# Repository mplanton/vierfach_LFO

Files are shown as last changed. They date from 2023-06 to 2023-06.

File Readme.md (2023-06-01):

# Vierfach LFO Eurorack Module

This is a quadruple LFO eurorack module.
The original LFO schematic is found in Barry Klein's [Electronic music circuits](https://archive.org/details/electronic-music-circuits/page/n71/mode/2up) on page 70.

Every LFO features a switchable output for pulse, triangle or sine.

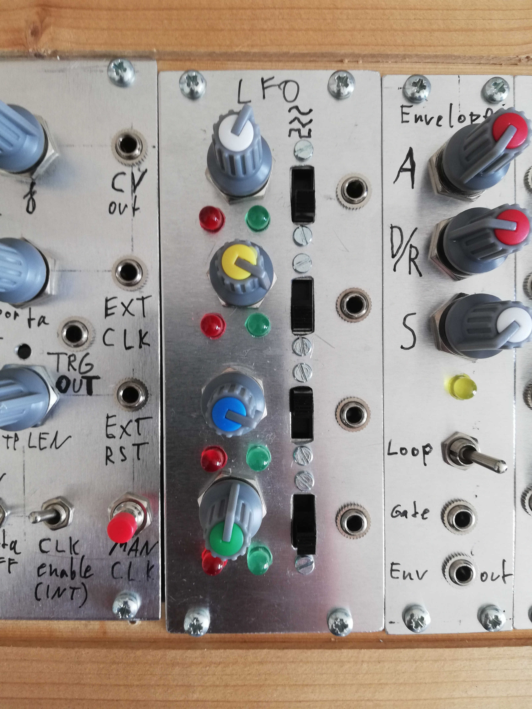
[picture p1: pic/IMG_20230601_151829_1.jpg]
Vierfach LFO module.


See the [pictures](pic/) for the assembly process.
The module is a rough prototype I built for my own purposes and I hope you may find it useful for your own projects.

Manuel Planton 2022

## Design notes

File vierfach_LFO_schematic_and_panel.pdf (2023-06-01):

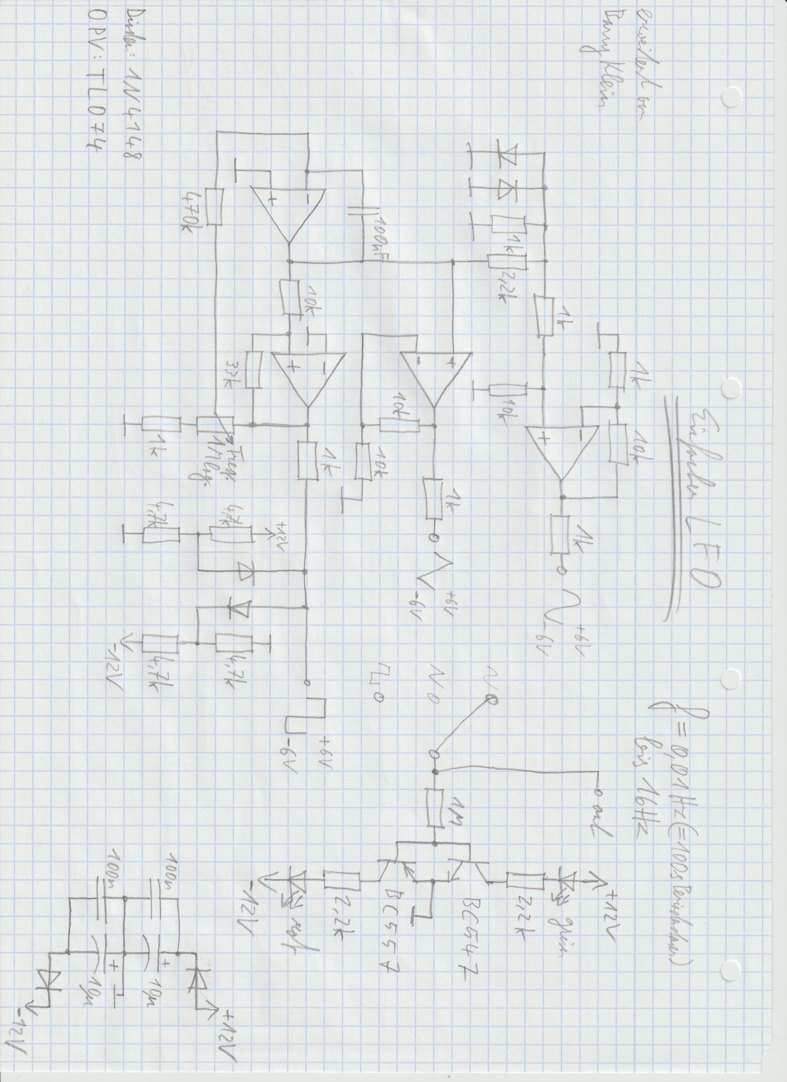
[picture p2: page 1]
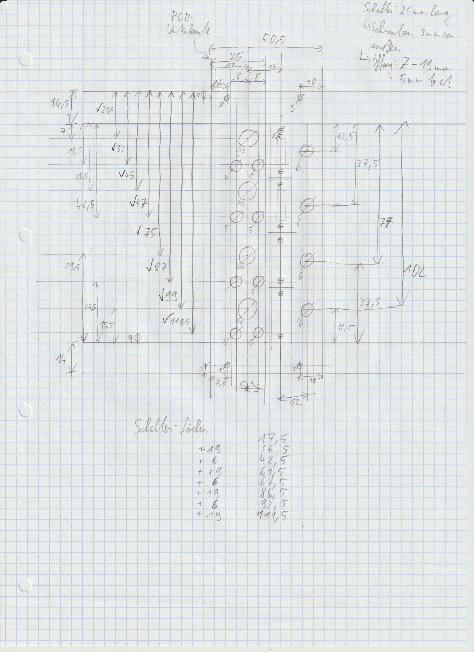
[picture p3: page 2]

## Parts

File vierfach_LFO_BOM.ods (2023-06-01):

Reference | Value | Footprint
C101 | 10u | Capacitor_THT:CP_Radial_D5.0mm_P2.50mm
C102 | 10u | Capacitor_THT:CP_Radial_D5.0mm_P2.50mm
C201 | 100n | Capacitor_SMD:C_0805_2012Metric_Pad1.18x1.45mm_HandSolder
C202 | 100n | Capacitor_SMD:C_0805_2012Metric_Pad1.18x1.45mm_HandSolder
C203 | 100n | Capacitor_SMD:C_0805_2012Metric_Pad1.18x1.45mm_HandSolder
C301 | 100n | Capacitor_SMD:C_0805_2012Metric_Pad1.18x1.45mm_HandSolder
C302 | 100n | Capacitor_SMD:C_0805_2012Metric_Pad1.18x1.45mm_HandSolder
C303 | 100n | Capacitor_SMD:C_0805_2012Metric_Pad1.18x1.45mm_HandSolder
C401 | 100n | Capacitor_SMD:C_0805_2012Metric_Pad1.18x1.45mm_HandSolder
C402 | 100n | Capacitor_SMD:C_0805_2012Metric_Pad1.18x1.45mm_HandSolder
C403 | 100n | Capacitor_SMD:C_0805_2012Metric_Pad1.18x1.45mm_HandSolder
C501 | 100n | Capacitor_SMD:C_0805_2012Metric_Pad1.18x1.45mm_HandSolder
C502 | 100n | Capacitor_SMD:C_0805_2012Metric_Pad1.18x1.45mm_HandSolder
C503 | 100n | Capacitor_SMD:C_0805_2012Metric_Pad1.18x1.45mm_HandSolder
R202 | 10k | Resistor_SMD:R_0805_2012Metric_Pad1.20x1.40mm_HandSolder
R207 | 10k | Resistor_SMD:R_0805_2012Metric_Pad1.20x1.40mm_HandSolder
R212 | 10k | Resistor_SMD:R_0805_2012Metric_Pad1.20x1.40mm_HandSolder
R213 | 10k | Resistor_SMD:R_0805_2012Metric_Pad1.20x1.40mm_HandSolder
R215 | 10k | Resistor_SMD:R_0805_2012Metric_Pad1.20x1.40mm_HandSolder
R201 | 1k | Resistor_SMD:R_0805_2012Metric_Pad1.20x1.40mm_HandSolder
R204 | 1k | Resistor_THT:R_Axial_DIN0207_L6.3mm_D2.5mm_P10.16mm_Horizontal
R205 | 1k | Resistor_SMD:R_0805_2012Metric_Pad1.20x1.40mm_HandSolder
R208 | 1k | Resistor_SMD:R_0805_2012Metric_Pad1.20x1.40mm_HandSolder
R211 | 1k | Resistor_THT:R_Axial_DIN0207_L6.3mm_D2.5mm_P10.16mm_Horizontal
R214 | 1k | Resistor_THT:R_Axial_DIN0207_L6.3mm_D2.5mm_P10.16mm_Horizontal
R222 | 1k | Resistor_SMD:R_0805_2012Metric_Pad1.20x1.40mm_HandSolder
R206 | 1M | Resistor_SMD:R_0805_2012Metric_Pad1.20x1.40mm_HandSolder
R203 | 2.2k | Resistor_SMD:R_0805_2012Metric_Pad1.20x1.40mm_HandSolder
R209 | 2.2k | Resistor_SMD:R_0805_2012Metric_Pad1.20x1.40mm_HandSolder
R210 | 2.2k | Resistor_SMD:R_0805_2012Metric_Pad1.20x1.40mm_HandSolder
R218 | 33k | Resistor_SMD:R_0805_2012Metric_Pad1.20x1.40mm_HandSolder
R216 | 4.7k | Resistor_SMD:R_0805_2012Metric_Pad1.20x1.40mm_HandSolder
R217 | 4.7k | Resistor_SMD:R_0805_2012Metric_Pad1.20x1.40mm_HandSolder
R219 | 4.7k | Resistor_SMD:R_0805_2012Metric_Pad1.20x1.40mm_HandSolder
R220 | 4.7k | Resistor_SMD:R_0805_2012Metric_Pad1.20x1.40mm_HandSolder
R221 | 470k | Resistor_SMD:R_0805_2012Metric_Pad1.20x1.40mm_HandSolder
R302 | 10k | Resistor_SMD:R_0805_2012Metric_Pad1.20x1.40mm_HandSolder
R307 | 10k | Resistor_SMD:R_0805_2012Metric_Pad1.20x1.40mm_HandSolder
R312 | 10k | Resistor_SMD:R_0805_2012Metric_Pad1.20x1.40mm_HandSolder
R313 | 10k | Resistor_SMD:R_0805_2012Metric_Pad1.20x1.40mm_HandSolder
R315 | 10k | Resistor_SMD:R_0805_2012Metric_Pad1.20x1.40mm_HandSolder
R301 | 1k | Resistor_SMD:R_0805_2012Metric_Pad1.20x1.40mm_HandSolder
R304 | 1k | Resistor_THT:R_Axial_DIN0207_L6.3mm_D2.5mm_P10.16mm_Horizontal
R305 | 1k | Resistor_SMD:R_0805_2012Metric_Pad1.20x1.40mm_HandSolder
R308 | 1k | Resistor_SMD:R_0805_2012Metric_Pad1.20x1.40mm_HandSolder
R311 | 1k | Resistor_THT:R_Axial_DIN0207_L6.3mm_D2.5mm_P10.16mm_Horizontal
R314 | 1k | Resistor_THT:R_Axial_DIN0207_L6.3mm_D2.5mm_P10.16mm_Horizontal
R322 | 1k | Resistor_SMD:R_0805_2012Metric_Pad1.20x1.40mm_HandSolder
R306 | 1M | Resistor_SMD:R_0805_2012Metric_Pad1.20x1.40mm_HandSolder
R303 | 2.2k | Resistor_SMD:R_0805_2012Metric_Pad1.20x1.40mm_HandSolder
R309 | 2.2k | Resistor_SMD:R_0805_2012Metric_Pad1.20x1.40mm_HandSolder
R310 | 2.2k | Resistor_SMD:R_0805_2012Metric_Pad1.20x1.40mm_HandSolder
R318 | 33k | Resistor_SMD:R_0805_2012Metric_Pad1.20x1.40mm_HandSolder
R316 | 4.7k | Resistor_SMD:R_0805_2012Metric_Pad1.20x1.40mm_HandSolder
R317 | 4.7k | Resistor_SMD:R_0805_2012Metric_Pad1.20x1.40mm_HandSolder
R319 | 4.7k | Resistor_SMD:R_0805_2012Metric_Pad1.20x1.40mm_HandSolder
R320 | 4.7k | Resistor_SMD:R_0805_2012Metric_Pad1.20x1.40mm_HandSolder
R321 | 470k | Resistor_SMD:R_0805_2012Metric_Pad1.20x1.40mm_HandSolder
R402 | 10k | Resistor_SMD:R_0805_2012Metric_Pad1.20x1.40mm_HandSolder
R407 | 10k | Resistor_SMD:R_0805_2012Metric_Pad1.20x1.40mm_HandSolder
R412 | 10k | Resistor_SMD:R_0805_2012Metric_Pad1.20x1.40mm_HandSolder
R413 | 10k | Resistor_SMD:R_0805_2012Metric_Pad1.20x1.40mm_HandSolder
R415 | 10k | Resistor_SMD:R_0805_2012Metric_Pad1.20x1.40mm_HandSolder
R401 | 1k | Resistor_SMD:R_0805_2012Metric_Pad1.20x1.40mm_HandSolder
R404 | 1k | Resistor_THT:R_Axial_DIN0207_L6.3mm_D2.5mm_P10.16mm_Horizontal
R405 | 1k | Resistor_SMD:R_0805_2012Metric_Pad1.20x1.40mm_HandSolder
R408 | 1k | Resistor_SMD:R_0805_2012Metric_Pad1.20x1.40mm_HandSolder
R411 | 1k | Resistor_THT:R_Axial_DIN0207_L6.3mm_D2.5mm_P10.16mm_Horizontal
R414 | 1k | Resistor_THT:R_Axial_DIN0207_L6.3mm_D2.5mm_P10.16mm_Horizontal
R422 | 1k | Resistor_SMD:R_0805_2012Metric_Pad1.20x1.40mm_HandSolder
R406 | 1M | Resistor_SMD:R_0805_2012Metric_Pad1.20x1.40mm_HandSolder
R403 | 2.2k | Resistor_SMD:R_0805_2012Metric_Pad1.20x1.40mm_HandSolder
R409 | 2.2k | Resistor_SMD:R_0805_2012Metric_Pad1.20x1.40mm_HandSolder
R410 | 2.2k | Resistor_SMD:R_0805_2012Metric_Pad1.20x1.40mm_HandSolder
R418 | 33k | Resistor_SMD:R_0805_2012Metric_Pad1.20x1.40mm_HandSolder
R416 | 4.7k | Resistor_SMD:R_0805_2012Metric_Pad1.20x1.40mm_HandSolder
R417 | 4.7k | Resistor_SMD:R_0805_2012Metric_Pad1.20x1.40mm_HandSolder
R419 | 4.7k | Resistor_SMD:R_0805_2012Metric_Pad1.20x1.40mm_HandSolder
R420 | 4.7k | Resistor_SMD:R_0805_2012Metric_Pad1.20x1.40mm_HandSolder
R421 | 470k | Resistor_SMD:R_0805_2012Metric_Pad1.20x1.40mm_HandSolder
R502 | 10k | Resistor_SMD:R_0805_2012Metric_Pad1.20x1.40mm_HandSolder
R507 | 10k | Resistor_SMD:R_0805_2012Metric_Pad1.20x1.40mm_HandSolder
R512 | 10k | Resistor_SMD:R_0805_2012Metric_Pad1.20x1.40mm_HandSolder
R513 | 10k | Resistor_SMD:R_0805_2012Metric_Pad1.20x1.40mm_HandSolder
R515 | 10k | Resistor_SMD:R_0805_2012Metric_Pad1.20x1.40mm_HandSolder
R501 | 1k | Resistor_SMD:R_0805_2012Metric_Pad1.20x1.40mm_HandSolder
R504 | 1k | Resistor_THT:R_Axial_DIN0207_L6.3mm_D2.5mm_P10.16mm_Horizontal
R505 | 1k | Resistor_SMD:R_0805_2012Metric_Pad1.20x1.40mm_HandSolder
R508 | 1k | Resistor_SMD:R_0805_2012Metric_Pad1.20x1.40mm_HandSolder
R511 | 1k | Resistor_THT:R_Axial_DIN0207_L6.3mm_D2.5mm_P10.16mm_Horizontal
R514 | 1k | Resistor_THT:R_Axial_DIN0207_L6.3mm_D2.5mm_P10.16mm_Horizontal
R522 | 1k | Resistor_SMD:R_0805_2012Metric_Pad1.20x1.40mm_HandSolder
R506 | 1M | Resistor_SMD:R_0805_2012Metric_Pad1.20x1.40mm_HandSolder
R503 | 2.2k | Resistor_SMD:R_0805_2012Metric_Pad1.20x1.40mm_HandSolder
R509 | 2.2k | Resistor_SMD:R_0805_2012Metric_Pad1.20x1.40mm_HandSolder
R510 | 2.2k | Resistor_SMD:R_0805_2012Metric_Pad1.20x1.40mm_HandSolder
R518 | 33k | Resistor_SMD:R_0805_2012Metric_Pad1.20x1.40mm_HandSolder
R516 | 4.7k | Resistor_SMD:R_0805_2012Metric_Pad1.20x1.40mm_HandSolder
R517 | 4.7k | Resistor_SMD:R_0805_2012Metric_Pad1.20x1.40mm_HandSolder
R519 | 4.7k | Resistor_SMD:R_0805_2012Metric_Pad1.20x1.40mm_HandSolder
R520 | 4.7k | Resistor_SMD:R_0805_2012Metric_Pad1.20x1.40mm_HandSolder
R521 | 470k | Resistor_SMD:R_0805_2012Metric_Pad1.20x1.40mm_HandSolder
D202 | 1N4148 | Diode_THT:D_DO-35_SOD27_P7.62mm_Horizontal
D203 | 1N4148 | Diode_THT:D_DO-35_SOD27_P7.62mm_Horizontal
D205 | 1N4148 | Diode_THT:D_DO-35_SOD27_P7.62mm_Horizontal
D206 | 1N4148 | Diode_THT:D_DO-35_SOD27_P7.62mm_Horizontal
D302 | 1N4148 | Diode_THT:D_DO-35_SOD27_P7.62mm_Horizontal
D303 | 1N4148 | Diode_THT:D_DO-35_SOD27_P7.62mm_Horizontal
D305 | 1N4148 | Diode_THT:D_DO-35_SOD27_P7.62mm_Horizontal
D306 | 1N4148 | Diode_THT:D_DO-35_SOD27_P7.62mm_Horizontal
D402 | 1N4148 | Diode_THT:D_DO-35_SOD27_P7.62mm_Horizontal
D403 | 1N4148 | Diode_THT:D_DO-35_SOD27_P7.62mm_Horizontal
D405 | 1N4148 | Diode_THT:D_DO-35_SOD27_P7.62mm_Horizontal
D406 | 1N4148 | Diode_THT:D_DO-35_SOD27_P7.62mm_Horizontal
D502 | 1N4148 | Diode_THT:D_DO-35_SOD27_P7.62mm_Horizontal
D503 | 1N4148 | Diode_THT:D_DO-35_SOD27_P7.62mm_Horizontal
D505 | 1N4148 | Diode_THT:D_DO-35_SOD27_P7.62mm_Horizontal
D506 | 1N4148 | Diode_THT:D_DO-35_SOD27_P7.62mm_Horizontal
D101 | 1N5817 | Diode_THT:D_DO-41_SOD81_P10.16mm_Horizontal
D102 | 1N5817 | Diode_THT:D_DO-41_SOD81_P10.16mm_Horizontal
D201 | green | LED_THT:LED_D5.0mm
D301 | green | LED_THT:LED_D5.0mm
D401 | green | LED_THT:LED_D5.0mm
D501 | green | LED_THT:LED_D5.0mm
D204 | red | LED_THT:LED_D5.0mm
D304 | red | LED_THT:LED_D5.0mm
D404 | red | LED_THT:LED_D5.0mm
D504 | red | LED_THT:LED_D5.0mm
Q201 | BC547 | Package_TO_SOT_THT:TO-92_Inline_Wide
Q202 | BC557 | Package_TO_SOT_THT:TO-92_Inline_Wide
Q301 | BC547 | Package_TO_SOT_THT:TO-92_Inline_Wide
Q302 | BC557 | Package_TO_SOT_THT:TO-92_Inline_Wide
Q401 | BC547 | Package_TO_SOT_THT:TO-92_Inline_Wide
Q402 | BC557 | Package_TO_SOT_THT:TO-92_Inline_Wide
Q501 | BC547 | Package_TO_SOT_THT:TO-92_Inline_Wide
Q502 | BC557 | Package_TO_SOT_THT:TO-92_Inline_Wide
R_freq201 | 1M | Potentiometer_THT:Potentiometer_Piher_PC-16_Single_Horizontal
R_freq301 | 1M | Potentiometer_THT:Potentiometer_Piher_PC-16_Single_Horizontal
R_freq401 | 1M | Potentiometer_THT:Potentiometer_Piher_PC-16_Single_Horizontal
R_freq501 | 1M | Potentiometer_THT:Potentiometer_Piher_PC-16_Single_Horizontal
U201 | TL074 | Package_DIP:DIP-14_W7.62mm_Socket
U301 | TL074 | Package_DIP:DIP-14_W7.62mm_Socket
U401 | TL074 | Package_DIP:DIP-14_W7.62mm_Socket
U501 | TL074 | Package_DIP:DIP-14_W7.62mm_Socket
J101 | Conn_02x05_Odd_Even | Connector_PinHeader_2.54mm:PinHeader_2x05_P2.54mm_Vertical
J201 | LEDs_IN_Conn_01x01_Female | Connector_PinHeader_2.54mm:PinHeader_1x01_P2.54mm_Vertical
J202 | sine_OUT_Conn_01x01_Female | Connector_PinHeader_2.54mm:PinHeader_1x01_P2.54mm_Vertical
J203 | tri_OUT_Conn_01x01_Female | Connector_PinHeader_2.54mm:PinHeader_1x01_P2.54mm_Vertical
J204 | square_OUT_Conn_01x01_Female | Connector_PinHeader_2.54mm:PinHeader_1x01_P2.54mm_Vertical
J301 | LEDs_IN_Conn_01x01_Female | Connector_PinHeader_2.54mm:PinHeader_1x01_P2.54mm_Vertical
J302 | sine_OUT_Conn_01x01_Female | Connector_PinHeader_2.54mm:PinHeader_1x01_P2.54mm_Vertical
J303 | tri_OUT_Conn_01x01_Female | Connector_PinHeader_2.54mm:PinHeader_1x01_P2.54mm_Vertical
J304 | square_OUT_Conn_01x01_Female | Connector_PinHeader_2.54mm:PinHeader_1x01_P2.54mm_Vertical
J401 | LEDs_IN_Conn_01x01_Female | Connector_PinHeader_2.54mm:PinHeader_1x01_P2.54mm_Vertical
J402 | sine_OUT_Conn_01x01_Female | Connector_PinHeader_2.54mm:PinHeader_1x01_P2.54mm_Vertical
J403 | tri_OUT_Conn_01x01_Female | Connector_PinHeader_2.54mm:PinHeader_1x01_P2.54mm_Vertical
J404 | square_OUT_Conn_01x01_Female | Connector_PinHeader_2.54mm:PinHeader_1x01_P2.54mm_Vertical
J501 | LEDs_IN_Conn_01x01_Female | Connector_PinHeader_2.54mm:PinHeader_1x01_P2.54mm_Vertical
J502 | sine_OUT_Conn_01x01_Female | Connector_PinHeader_2.54mm:PinHeader_1x01_P2.54mm_Vertical
J503 | tri_OUT_Conn_01x01_Female | Connector_PinHeader_2.54mm:PinHeader_1x01_P2.54mm_Vertical
J504 | square_OUT_Conn_01x01_Female | Connector_PinHeader_2.54mm:PinHeader_1x01_P2.54mm_Vertical

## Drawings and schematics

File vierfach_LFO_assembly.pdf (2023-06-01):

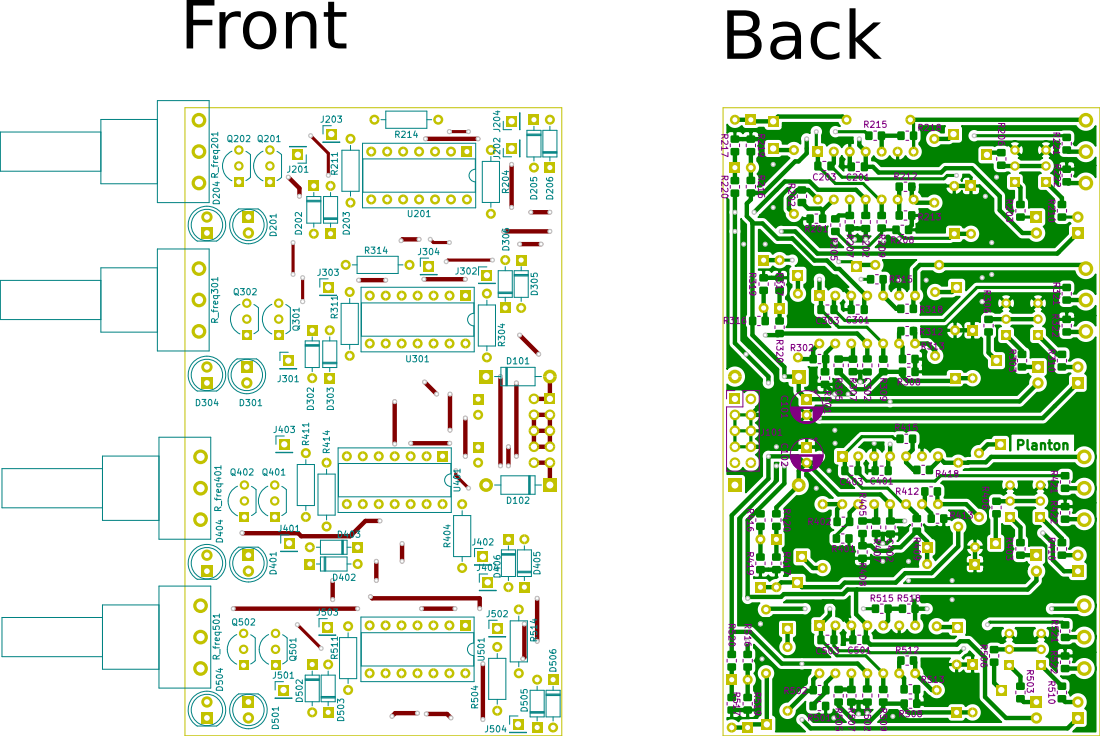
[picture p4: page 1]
Front; Back

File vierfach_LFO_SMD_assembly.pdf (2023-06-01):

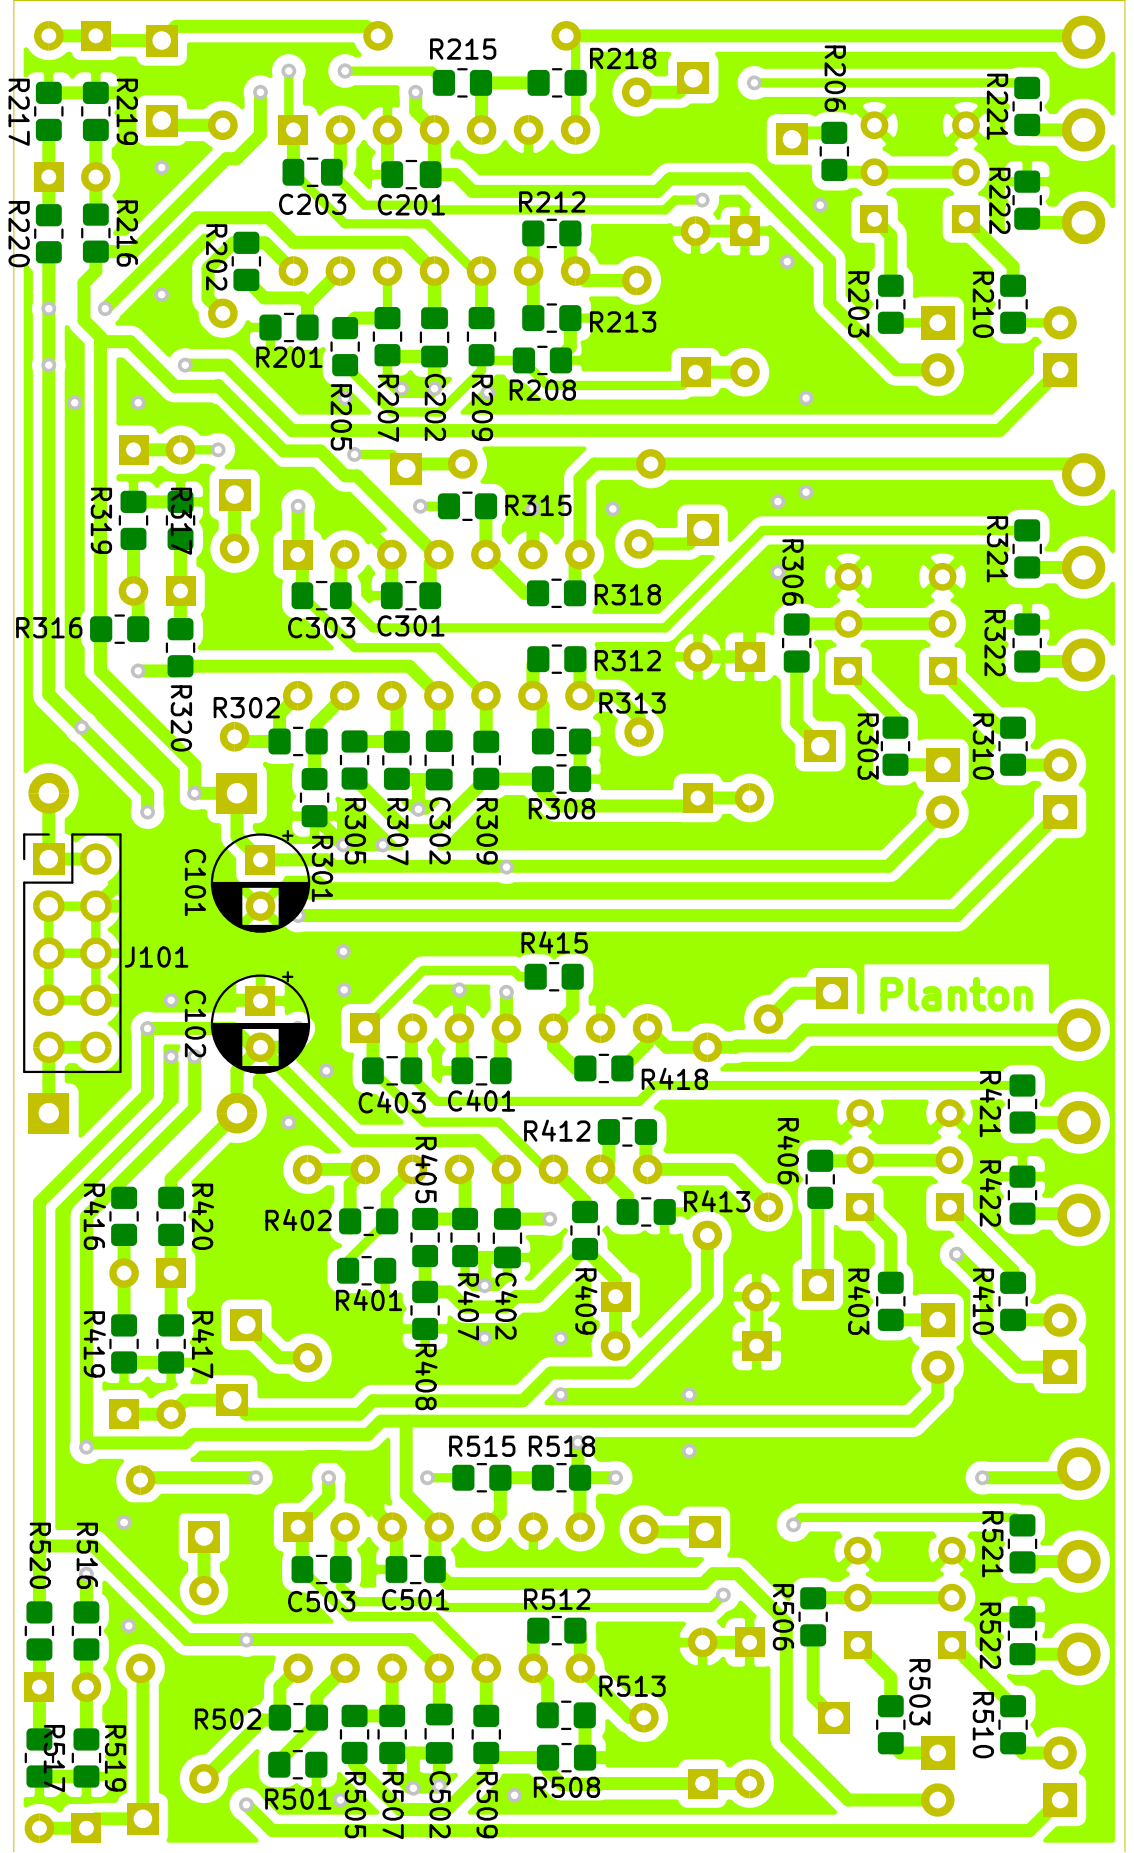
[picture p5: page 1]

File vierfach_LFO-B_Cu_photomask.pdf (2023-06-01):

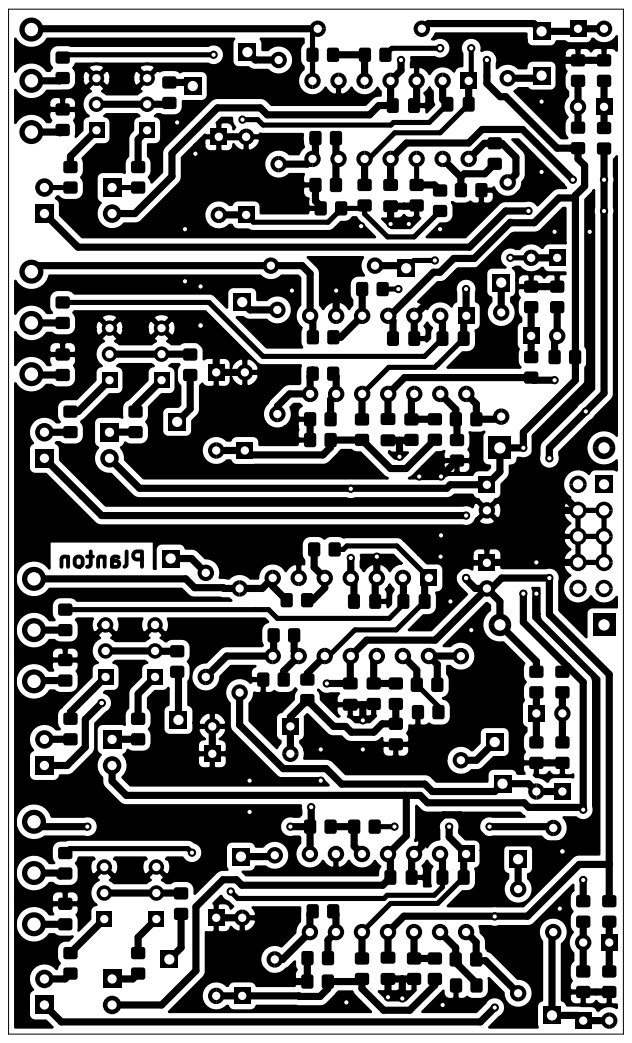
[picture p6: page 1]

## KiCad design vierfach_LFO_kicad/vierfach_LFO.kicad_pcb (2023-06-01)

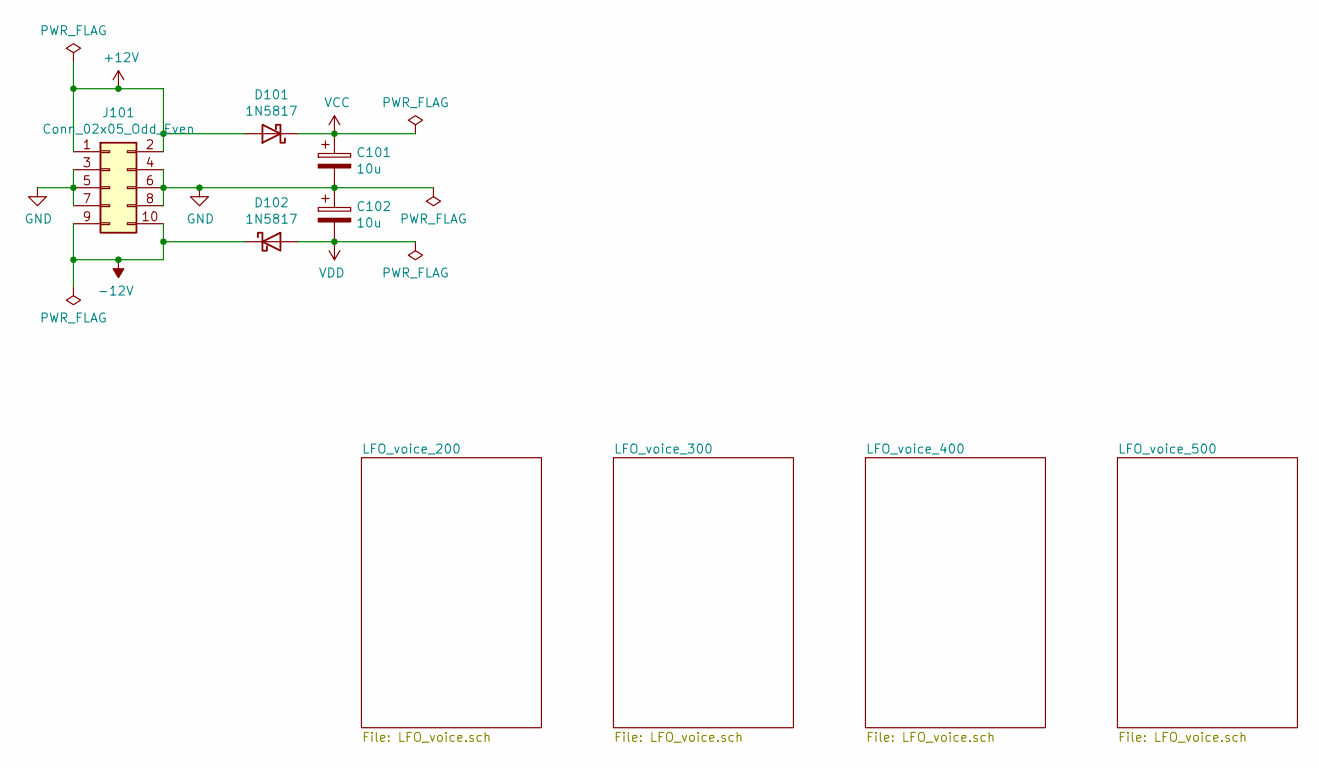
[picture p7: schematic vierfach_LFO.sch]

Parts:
C101, C102: 10u; CP_Radial_D5.0mm_P2.50mm
D101, D102: 1N5817; D_DO-41_SOD81_P10.16mm_Horizontal
J101: Conn_02x05_Odd_Even; PinHeader_2x05_P2.54mm_Vertical

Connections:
+12V: D101.2 (A), J101.1, J101.2
-12V: D102.1 (K), J101.9, J101.10
GND: C101.2, C102.1, J101.3, J101.4, J101.5, J101.6, J101.7, J101.8; also elsewhere on the board
VCC: C101.1, D101.1 (K); also elsewhere on the board
VDD: C102.2, D102.2 (A); also elsewhere on the board

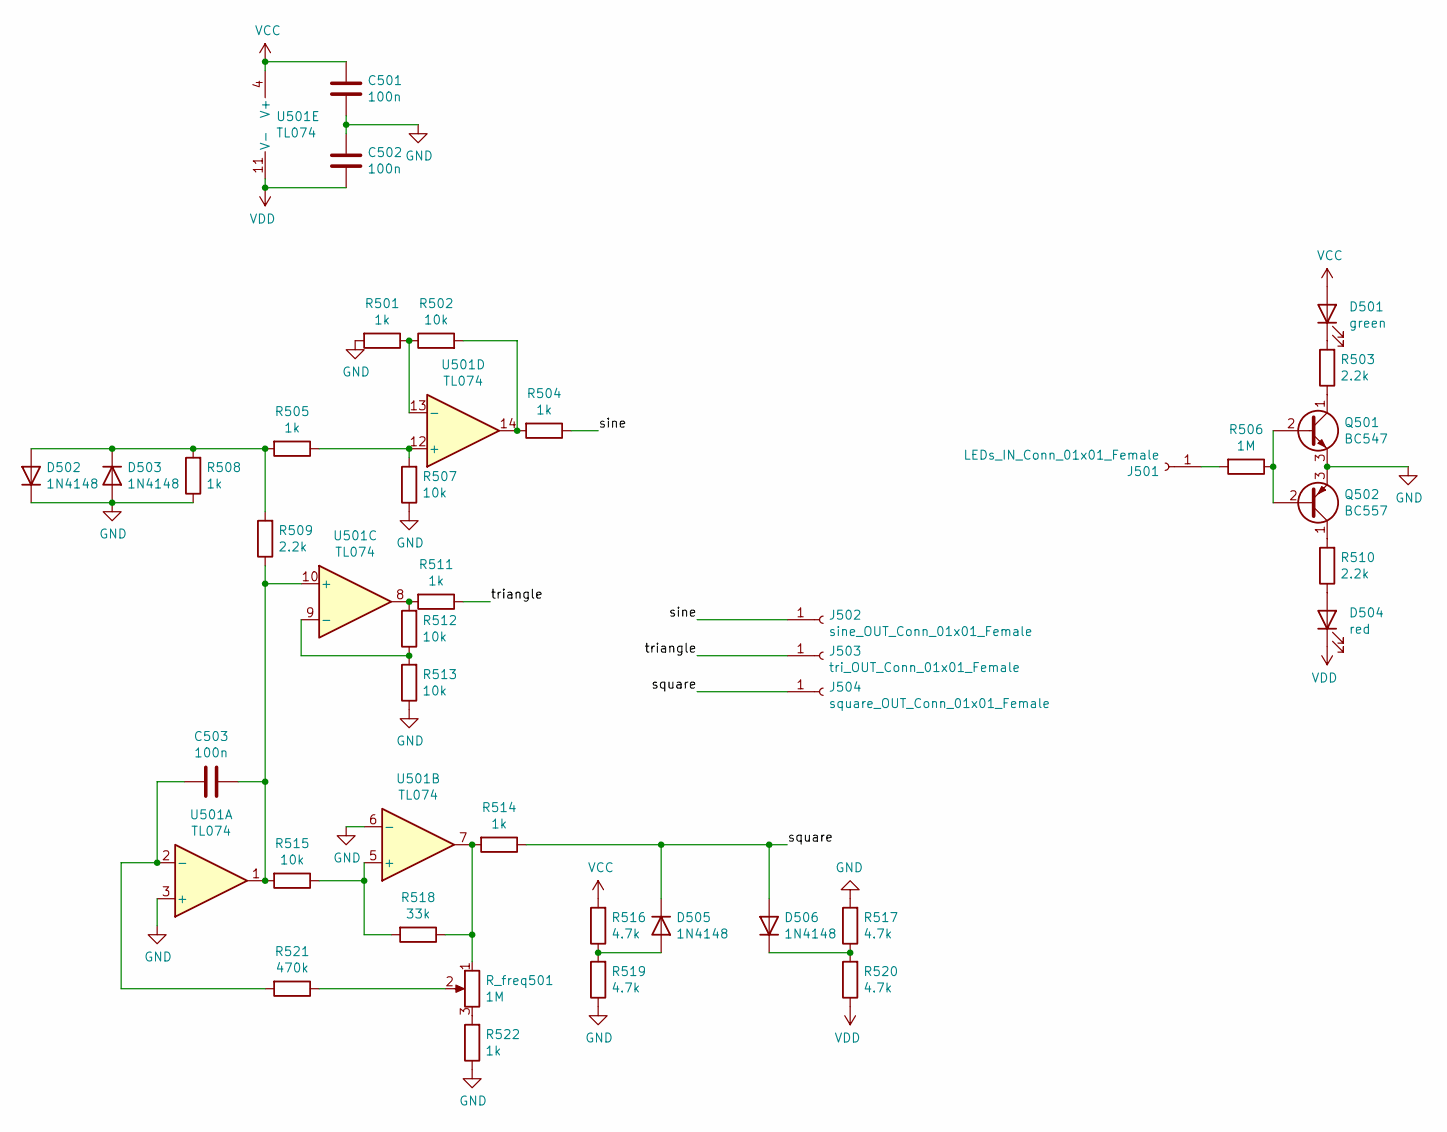
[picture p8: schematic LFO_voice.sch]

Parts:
C201, C202, C203: 100n; C_0805_2012Metric_Pad1.18x1.45mm_HandSolder
D201: green; LED_D5.0mm
D202, D203, D205, D206: 1N4148; D_DO-35_SOD27_P7.62mm_Horizontal
D204: red; LED_D5.0mm
J201: LEDs_IN_Conn_01x01_Female; PinHeader_1x01_P2.54mm_Vertical
J202: sine_OUT_Conn_01x01_Female; PinHeader_1x01_P2.54mm_Vertical
J203: tri_OUT_Conn_01x01_Female; PinHeader_1x01_P2.54mm_Vertical
J204: square_OUT_Conn_01x01_Female; PinHeader_1x01_P2.54mm_Vertical
Q201: BC547; TO-92_Inline_Wide
Q202: BC557; TO-92_Inline_Wide
R201, R205, R208, R222: 1k; R_0805_2012Metric_Pad1.20x1.40mm_HandSolder
R202, R207, R212, R213, R215: 10k; R_0805_2012Metric_Pad1.20x1.40mm_HandSolder
R203, R209, R210: 2.2k; R_0805_2012Metric_Pad1.20x1.40mm_HandSolder
R204, R211, R214: 1k; R_Axial_DIN0207_L6.3mm_D2.5mm_P10.16mm_Horizontal
R206: 1M; R_0805_2012Metric_Pad1.20x1.40mm_HandSolder
R216, R217, R219, R220: 4.7k; R_0805_2012Metric_Pad1.20x1.40mm_HandSolder
R218: 33k; R_0805_2012Metric_Pad1.20x1.40mm_HandSolder
R221: 470k; R_0805_2012Metric_Pad1.20x1.40mm_HandSolder
R_freq201: 1M; Potentiometer_Piher_PC-16_Single_Horizontal
U201: TL074; DIP-14_W7.62mm_Socket

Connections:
/LFO_voice_200/sine: J202.1, R204.1
/LFO_voice_200/square: D205.1 (K), D206.2 (A), J204.1, R214.1
/LFO_voice_200/triangle: J203.1, R211.1
GND: C201.2, C202.1, D202.1 (K), D203.2 (A), Q201.3 (E), Q202.3 (E), R201.2, R207.1, R208.1, R213.1, R217.2, R219.1, R222.1, U201.3 (+), U201.6 (-); also elsewhere on the board
unnamed: C203.1, R209.1, R215.2, U201.1, U201.10 (+)
unnamed: C203.2, R221.2, U201.2 (-)
unnamed: D201.1 (K), R203.2
unnamed: D202.2 (A), D203.1 (K), R205.2, R208.2, R209.2
unnamed: D204.2 (A), R210.1
unnamed: D205.2 (A), R216.1, R219.2
unnamed: D206.1 (K), R217.1, R220.2
unnamed: J201.1, R206.2
unnamed: Q201.1 (C), R203.1
unnamed: Q201.2 (B), Q202.2 (B), R206.1
unnamed: Q202.1 (C), R210.2
unnamed: R201.1, R202.1, U201.13 (-)
unnamed: R202.2, R204.2, U201.14
unnamed: R205.1, R207.2, U201.12 (+)
unnamed: R211.2, R212.2, U201.8
unnamed: R212.1, R213.2, U201.9 (-)
unnamed: R214.2, R218.1, R_freq201.1, U201.7
unnamed: R215.1, R218.2, U201.5 (+)
unnamed: R221.1, R_freq201.2
unnamed: R222.2, R_freq201.3
VCC: C201.1, D201.2 (A), R216.2, U201.4 (V+); also elsewhere on the board
VDD: C202.2, D204.1 (K), R220.1, U201.11 (V-); also elsewhere on the board

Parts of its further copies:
C301, C302, C303, C401, C402, C403, C501, C502, C503: 100n; C_0805_2012Metric_Pad1.18x1.45mm_HandSolder
D301, D401, D501: green; LED_D5.0mm
D302, D303, D305, D306, D402, D403, D405, D406, D502, D503, D505, D506: 1N4148; D_DO-35_SOD27_P7.62mm_Horizontal
D304, D404, D504: red; LED_D5.0mm
J301, J401, J501: LEDs_IN_Conn_01x01_Female; PinHeader_1x01_P2.54mm_Vertical
J302, J402, J502: sine_OUT_Conn_01x01_Female; PinHeader_1x01_P2.54mm_Vertical
J303, J403, J503: tri_OUT_Conn_01x01_Female; PinHeader_1x01_P2.54mm_Vertical
J304, J404, J504: square_OUT_Conn_01x01_Female; PinHeader_1x01_P2.54mm_Vertical
Q301, Q401, Q501: BC547; TO-92_Inline_Wide
Q302, Q402, Q502: BC557; TO-92_Inline_Wide
R301, R305, R308, R322, R401, R405, R408, R422, R501, R505, R508, R522: 1k; R_0805_2012Metric_Pad1.20x1.40mm_HandSolder
R302, R307, R312, R313, R315, R402, R407, R412, R413, R415, R502, R507, R512, R513, R515: 10k; R_0805_2012Metric_Pad1.20x1.40mm_HandSolder
R303, R309, R310, R403, R409, R410, R503, R509, R510: 2.2k; R_0805_2012Metric_Pad1.20x1.40mm_HandSolder
R304, R311, R314, R404, R411, R414, R504, R511, R514: 1k; R_Axial_DIN0207_L6.3mm_D2.5mm_P10.16mm_Horizontal
R306, R406, R506: 1M; R_0805_2012Metric_Pad1.20x1.40mm_HandSolder
R316, R317, R319, R320, R416, R417, R419, R420, R516, R517, R519, R520: 4.7k; R_0805_2012Metric_Pad1.20x1.40mm_HandSolder
R318, R418, R518: 33k; R_0805_2012Metric_Pad1.20x1.40mm_HandSolder
R321, R421, R521: 470k; R_0805_2012Metric_Pad1.20x1.40mm_HandSolder
R_freq301, R_freq401, R_freq501: 1M; Potentiometer_Piher_PC-16_Single_Horizontal
U301, U401, U501: TL074; DIP-14_W7.62mm_Socket

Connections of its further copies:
/LFO_voice_300/sine: J302.1, R304.1
/LFO_voice_300/square: D305.1 (K), D306.2 (A), J304.1, R314.1
/LFO_voice_300/triangle: J303.1, R311.1
/LFO_voice_400/sine: J402.1, R404.1
/LFO_voice_400/square: D405.1 (K), D406.2 (A), J404.1, R414.1
/LFO_voice_400/triangle: J403.1, R411.1
/LFO_voice_500/sine: J502.1, R504.1
/LFO_voice_500/square: D505.1 (K), D506.2 (A), J504.1, R514.1
/LFO_voice_500/triangle: J503.1, R511.1
GND: C301.2, C302.1, C401.2, C402.1, C501.2, C502.1, D302.1 (K), D303.2 (A), D402.1 (K), D403.2 (A), D502.1 (K), D503.2 (A), Q301.3 (E), Q302.3 (E), Q401.3 (E), Q402.3 (E), Q501.3 (E), Q502.3 (E), R301.2, R307.1, R308.1, R313.1, R317.2, R319.1, R322.1, R401.2, R407.1, R408.1, R413.1, R417.2, R419.1, R422.1, R501.2, R507.1, R508.1, R513.1, R517.2, R519.1, R522.1, U301.3 (+), U301.6 (-), U401.3 (+), U401.6 (-), U501.3 (+), U501.6 (-); also elsewhere on the board
unnamed: C303.1, R309.1, R315.2, U301.1, U301.10 (+)
unnamed: C303.2, R321.2, U301.2 (-)
unnamed: C403.1, R409.1, R415.2, U401.1, U401.10 (+)
unnamed: C403.2, R421.2, U401.2 (-)
unnamed: C503.1, R509.1, R515.2, U501.1, U501.10 (+)
unnamed: C503.2, R521.2, U501.2 (-)
unnamed: D301.1 (K), R303.2
unnamed: D302.2 (A), D303.1 (K), R305.2, R308.2, R309.2
unnamed: D304.2 (A), R310.1
unnamed: D305.2 (A), R316.1, R319.2
unnamed: D306.1 (K), R317.1, R320.2
unnamed: D401.1 (K), R403.2
unnamed: D402.2 (A), D403.1 (K), R405.2, R408.2, R409.2
unnamed: D404.2 (A), R410.1
unnamed: D405.2 (A), R416.1, R419.2
unnamed: D406.1 (K), R417.1, R420.2
unnamed: D501.1 (K), R503.2
unnamed: D502.2 (A), D503.1 (K), R505.2, R508.2, R509.2
unnamed: D504.2 (A), R510.1
unnamed: D505.2 (A), R516.1, R519.2
unnamed: D506.1 (K), R517.1, R520.2
unnamed: J301.1, R306.2
unnamed: J401.1, R406.2
unnamed: J501.1, R506.2
unnamed: Q301.1 (C), R303.1
unnamed: Q301.2 (B), Q302.2 (B), R306.1
unnamed: Q302.1 (C), R310.2
unnamed: Q401.1 (C), R403.1
unnamed: Q401.2 (B), Q402.2 (B), R406.1
unnamed: Q402.1 (C), R410.2
unnamed: Q501.1 (C), R503.1
unnamed: Q501.2 (B), Q502.2 (B), R506.1
unnamed: Q502.1 (C), R510.2
unnamed: R301.1, R302.1, U301.13 (-)
unnamed: R302.2, R304.2, U301.14
unnamed: R305.1, R307.2, U301.12 (+)
unnamed: R311.2, R312.2, U301.8
unnamed: R312.1, R313.2, U301.9 (-)
unnamed: R314.2, R318.1, R_freq301.1, U301.7
unnamed: R315.1, R318.2, U301.5 (+)
unnamed: R321.1, R_freq301.2
unnamed: R322.2, R_freq301.3
unnamed: R401.1, R402.1, U401.13 (-)
unnamed: R402.2, R404.2, U401.14
unnamed: R405.1, R407.2, U401.12 (+)
unnamed: R411.2, R412.2, U401.8
unnamed: R412.1, R413.2, U401.9 (-)
unnamed: R414.2, R418.1, R_freq401.1, U401.7
unnamed: R415.1, R418.2, U401.5 (+)
unnamed: R421.1, R_freq401.2
unnamed: R422.2, R_freq401.3
unnamed: R501.1, R502.1, U501.13 (-)
unnamed: R502.2, R504.2, U501.14
unnamed: R505.1, R507.2, U501.12 (+)
unnamed: R511.2, R512.2, U501.8
unnamed: R512.1, R513.2, U501.9 (-)
unnamed: R514.2, R518.1, R_freq501.1, U501.7
unnamed: R515.1, R518.2, U501.5 (+)
unnamed: R521.1, R_freq501.2
unnamed: R522.2, R_freq501.3
VCC: C301.1, C401.1, C501.1, D301.2 (A), D401.2 (A), D501.2 (A), R316.2, R416.2, R516.2, U301.4 (V+), U401.4 (V+), U501.4 (V+); also elsewhere on the board
VDD: C302.2, C402.2, C502.2, D304.1 (K), D404.1 (K), D504.1 (K), R320.1, R420.1, R520.1, U301.11 (V-), U401.11 (V-), U501.11 (V-); also elsewhere on the board

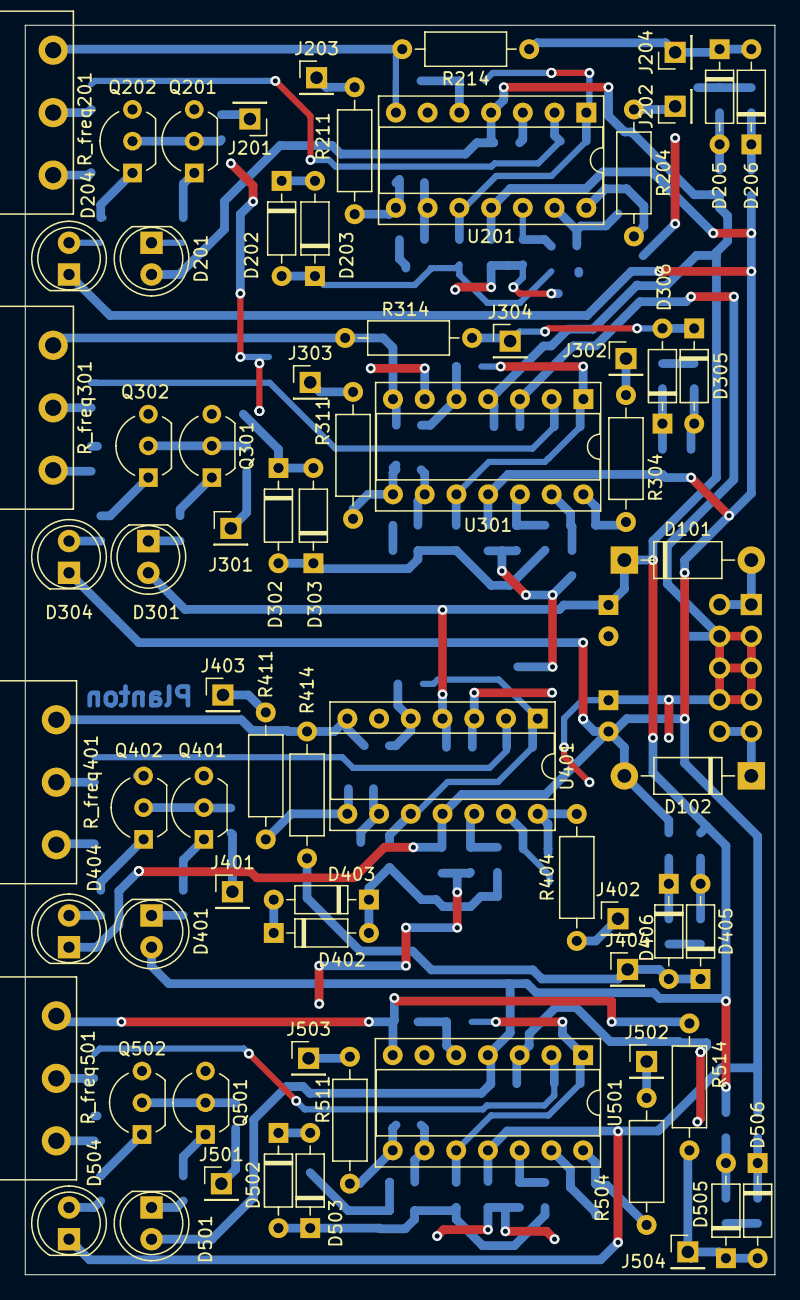
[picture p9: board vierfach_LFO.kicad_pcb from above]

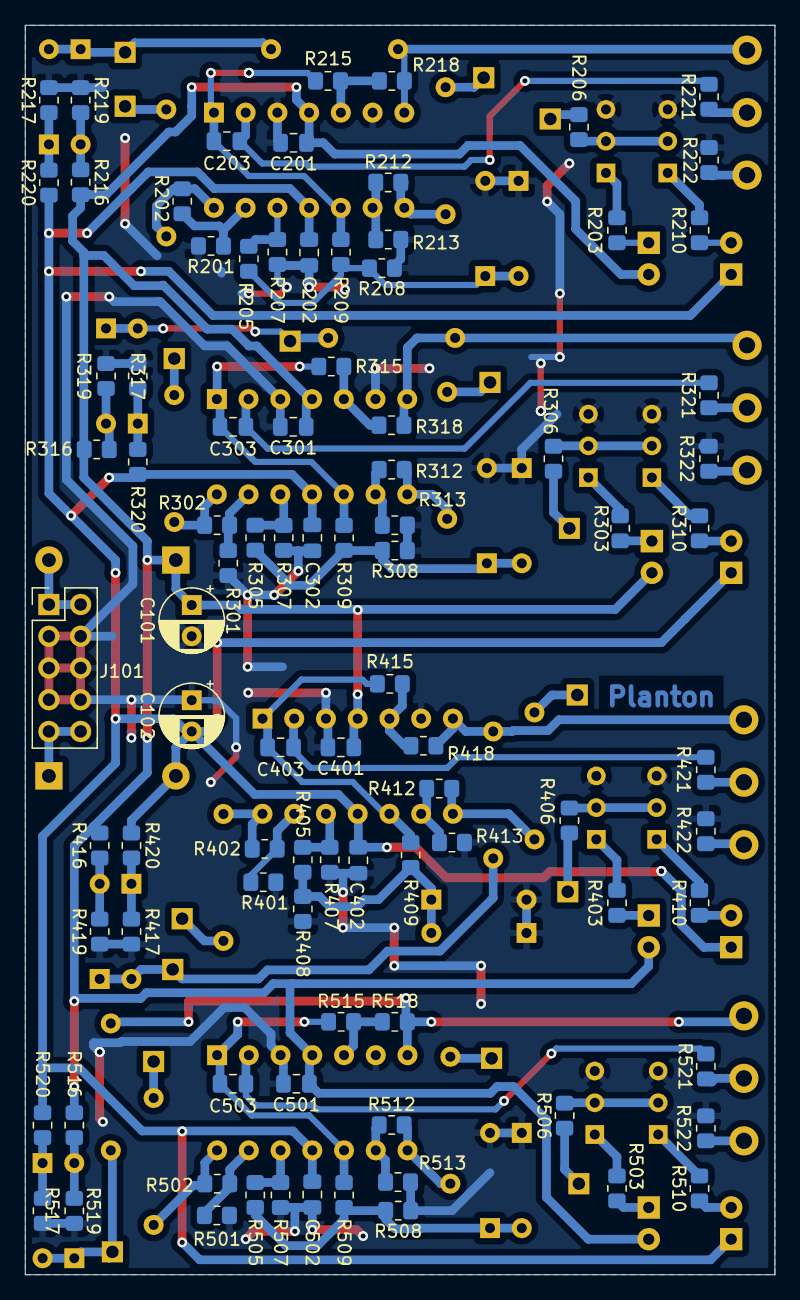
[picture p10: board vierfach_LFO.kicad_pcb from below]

Board: 2 copper layers, 60.0 x 100.0 mm, 161 parts (91 on the bottom side), 97 nets.
